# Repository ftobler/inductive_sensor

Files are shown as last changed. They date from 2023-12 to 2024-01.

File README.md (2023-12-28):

# inductive sensor with STM32

This is a open source inductive sensor using a STM32G030K8T6 MCU.

pcb-inductive-sensor v1

---

PCB has been made with Eagle, Software with STM32CubeIDE.

The sensor is capable of sub mm accuracy. There might be linearity errors.

The TX coil is driven with 125kHz. A new measurement can be made every 50ms. The speed is limited mainly due to lack of processing power and FPU. During one measurement, the TX coil is ON for 2.8ms. During the short ON time, data is gathered which is later processed. The amount which can be gathered is limited by RAM available.

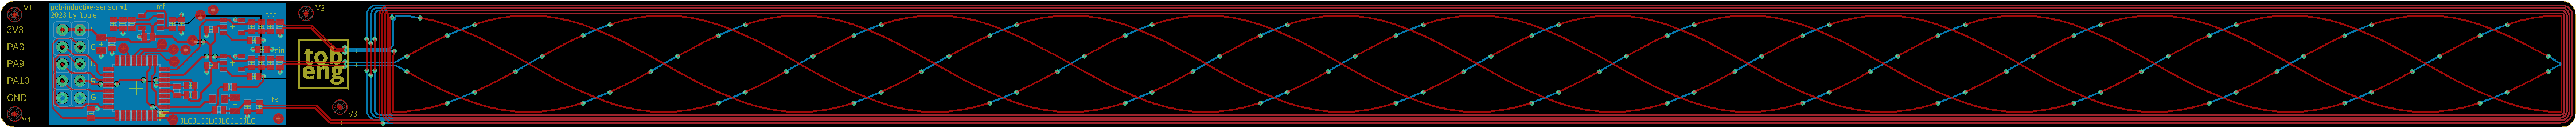
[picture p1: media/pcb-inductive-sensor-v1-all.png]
pcb-inductive-sensor v1


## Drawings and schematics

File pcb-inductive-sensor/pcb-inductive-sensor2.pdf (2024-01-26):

GND ¹⁰⁰n +3V³ | +3V³ GND
GND ⁺³V³ | 100n

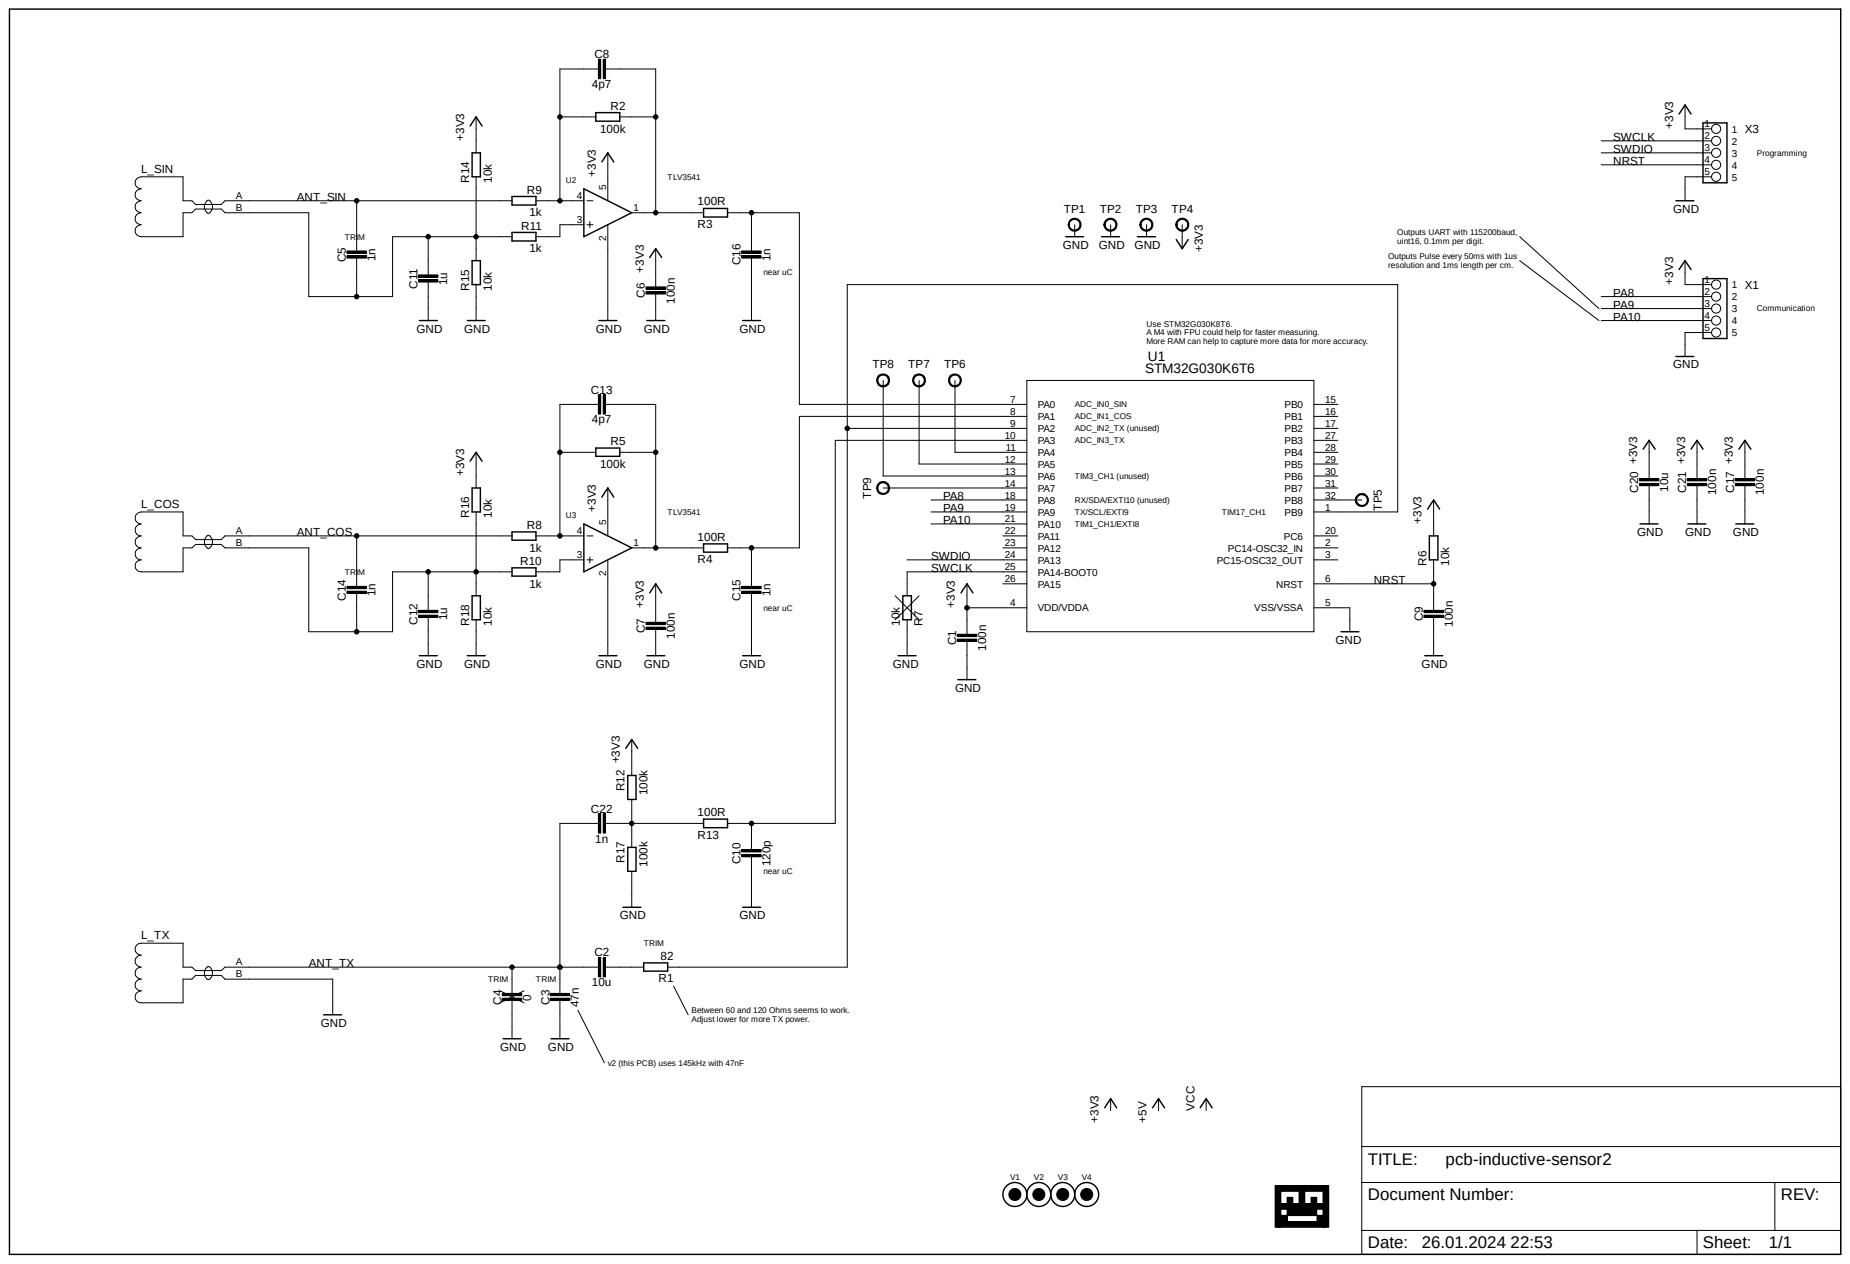
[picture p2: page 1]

Outputs UART with 115200baud,
uint16, 0.1mm per digit.
Outputs Pulse every 50ms with 1us
resolution and 1ms length per cm.

Use STM32G030K8T6.
A M4 with FPU could help for faster measuring.
More RAM can help to capture more data for more accuracy.

PA1 8
PA2 9
PA3 10
PA4 11

Between 60 and 120 Ohms seems to work.
Adjust lower for more TX power.

v2 (this PCB) uses 145kHz with 47nF

Document Number: | REV:

Date: 26.01.2024 22:53 | Sheet: 1/1

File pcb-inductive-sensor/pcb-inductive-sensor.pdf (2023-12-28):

GND ¹⁰⁰n +3V³ | +3V³ GND
GND ⁺³V³ | 100n

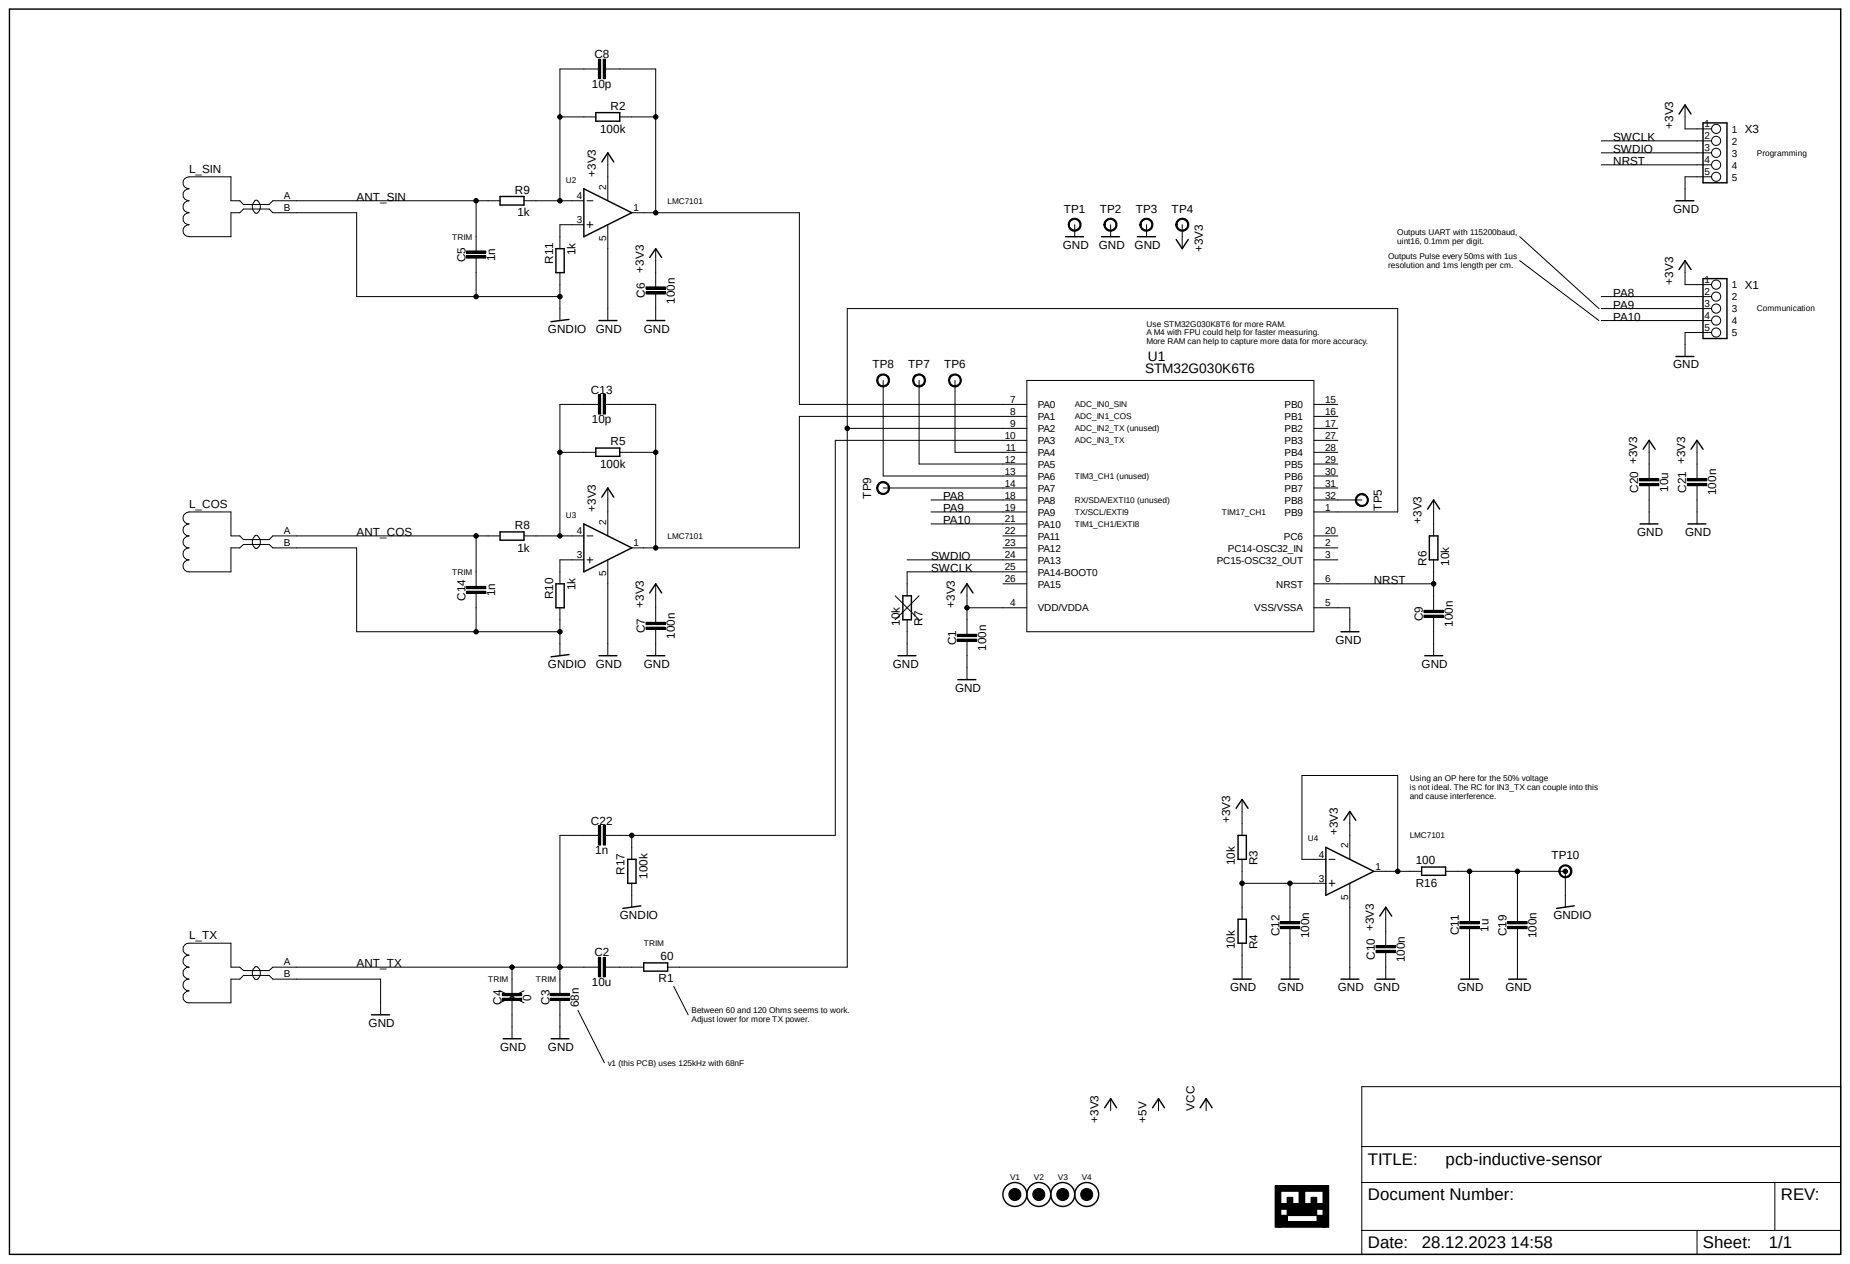
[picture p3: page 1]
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

Use STM32G030K8T6 for more RAM.
A M4 with FPU could help for faster measuring.
More RAM can help to capture more data for more accuracy.

PA1 8
PA2 9
PA3 10
PA4 11

Using an OP here for the 50% voltage
is not ideal. The RC for IN3_TX can couple into this
and cause interference.

Between 60 and 120 Ohms seems to work.
Adjust lower for more TX power.

v1 (this PCB) uses 125kHz with 68nF

Document Number: | REV:

Date: 28.12.2023 14:58 | Sheet: 1/1

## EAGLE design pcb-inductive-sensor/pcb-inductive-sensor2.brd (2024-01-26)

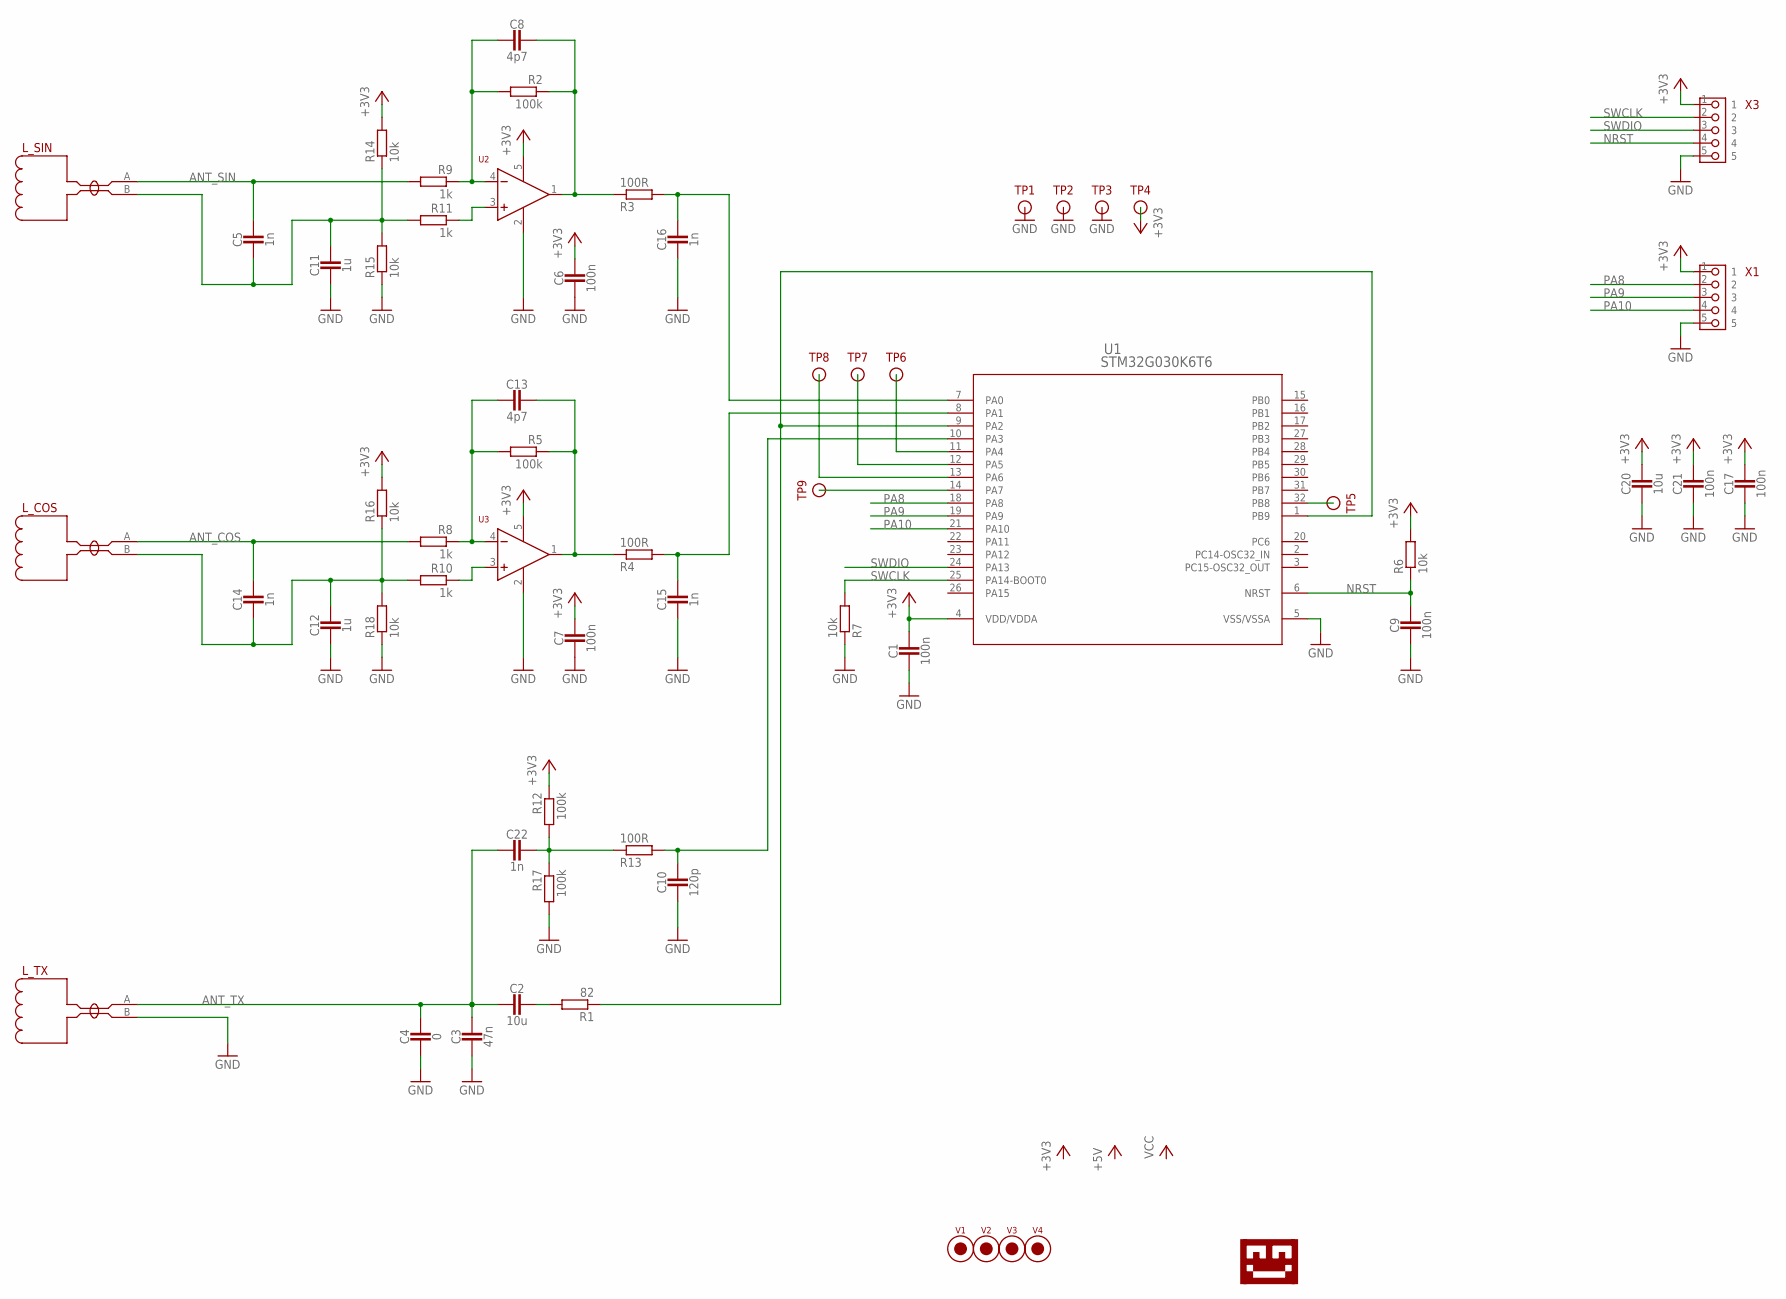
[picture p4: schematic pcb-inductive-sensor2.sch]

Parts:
C1, C6, C7, C9, C17, C21: 100n; 0603_CAP
C2, C20: 10u; 0805_CAP
C3: 47n; 0603_CAP
C4: 0; 0603_CAP
C5, C14, C15, C16, C22: 1n; 0603_CAP
C8, C13: 4p7; 0603_CAP
C10: 120p; 0603_CAP
C11, C12: 1u; 0603_CAP
L_COS: INDUCTION_SENSOR; INDUCTIVE_SENSOR_NET_TIE
L_SIN: INDUCTION_SENSOR; INDUCTIVE_SENSOR_NET_TIE
L_TX: INDUCTION_SENSOR; INDUCTIVE_SENSOR_NET_TIE
R1: 82; 0805_RES
R2, R5, R12, R17: 100k; 0603-RES
R3, R4, R13: 100R; 0603-RES
R6, R7, R14, R15, R16, R18: 10k; 0603-RES
R8, R9, R10, R11: 1k; 0603-RES
TP1, TP2, TP3, TP4, TP5, TP6, TP7, TP8, TP9: TESTPIN; PIN-SMD-1X1-TEST_1M5
U1: STM32G030K6T6; LQFP-32
U2, U3: OPAMP-TLV3541IDBVT; SOT-23-5
U$1: LOGO-TOBENG-1MM-FINISH; TOBENG-1MM-FINISH
V1, V2, V3, V4: FIDUCIAL2MM; FIDUCIAL_2MM
X1, X3: PIN_5X1HD; PIN_5X1_HD

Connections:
+3V3: C1.1, C6.1, C7.1, C17.1, C20.P$1 (1), C21.1, R6.2, R12.1, R14.2, R16.2, TP4.1, U1.4 (VDD/VDDA), U2.5 (VCC), U3.5 (VCC), X1.1, X3.1
ANT_COS: C14.1, L_COS.A, R8.2
ANT_SIN: C5.1, L_SIN.A, R9.2
ANT_TX: C2.P$2 (2), C3.1, C4.1, C22.2, L_TX.A
ANT_TX1: R1.1, U1.1 (PB9), U1.9 (PA2)
GND: C1.2, C3.2, C4.2, C6.2, C7.2, C9.2, C10.2, C11.2, C12.2, C15.2, C16.2, C17.2, C20.P$2 (2), C21.2, L_TX.B, R7.1, R15.1, R17.2, R18.1, TP1.1, TP2.1, TP3.1, U1.5 (VSS/VSSA), U2.2 (GND), U3.2 (GND), X1.5, X3.5
unnamed: C16.1, R3.2, U1.7 (PA0)
unnamed: C15.1, R4.2, U1.8 (PA1)
unnamed: C10.1, R13.2, U1.10 (PA3)
unnamed: TP6.1, U1.11 (PA4)
unnamed: TP7.1, U1.12 (PA5)
unnamed: TP8.1, U1.13 (PA6)
unnamed: TP9.1, U1.14 (PA7)
unnamed: C8.1, R2.1, R3.1, U2.1 (OUT)
unnamed: C8.2, R2.2, R9.1, U2.4 (-)
unnamed: TP5.1, U1.32 (PB8)
unnamed: C13.1, R4.1, R5.1, U3.1 (OUT)
unnamed: C13.2, R5.2, R8.1, U3.4 (-)
unnamed: C22.1, R12.2, R13.1, R17.1
unnamed: R11.1, U2.3 (+)
unnamed: R10.1, U3.3 (+)
unnamed: C2.P$1 (1), R1.2
unnamed: C12.1, C14.2, L_COS.B, R10.2, R16.1, R18.2
unnamed: C5.2, C11.1, L_SIN.B, R11.2, R14.1, R15.2
NRST: C9.1, R6.1, U1.6 (NRST), X3.4
PA8: U1.18 (PA8), X1.2
PA9: U1.19 (PA9), X1.3
PA10: U1.21 (PA10), X1.4
SWCLK: R7.2, U1.25 (PA14-BOOT0), X3.2
SWDIO: U1.24 (PA13), X3.3

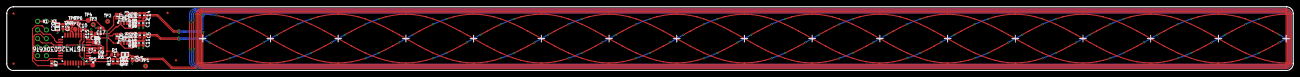
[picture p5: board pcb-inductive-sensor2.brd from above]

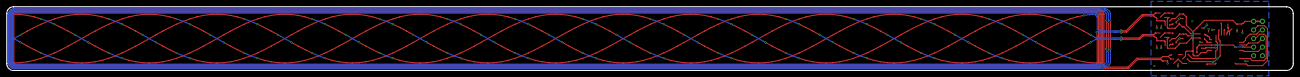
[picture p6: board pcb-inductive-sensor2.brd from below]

Board: 2 copper layers, 380.0 x 18.8 mm, 60 parts (2 on the bottom side), 30 nets.

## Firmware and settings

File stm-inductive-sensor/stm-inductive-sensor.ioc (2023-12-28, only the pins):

Mcu.UserName=STM32G030K8Tx
PA0.Signal=ADC1_IN0
PA1.Signal=ADC1_IN1
PA10.Signal=GPIO_Output
PA13.Signal=SYS_SWDIO
PA14-BOOT0.Signal=SYS_SWCLK
PA3.Signal=ADC1_IN3
PA8.Signal=S_TIM1_CH1
PA9.Signal=USART1_TX
PB7.Signal=USART1_RX
PB9.Signal=S_TIM17_CH1

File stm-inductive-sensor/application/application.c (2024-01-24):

/*
 * application.c
 *
 *  Created on: Dec 27, 2023
 *      Author: ftobler
 */


#include "application.h"
#include "stm32_hal.h"
#include "stdint.h"
#include "string.h"
#include "math.h"

extern ADC_HandleTypeDef hadc1;
extern DMA_HandleTypeDef hdma_adc1;
extern TIM_HandleTypeDef htim17;
extern TIM_HandleTypeDef htim1;
extern UART_HandleTypeDef huart1;

#define DATASIZE 1300  //maximize this. RAM amount and processing power is the limiting factor
#define DATAWIDTH 2
static uint16_t dma_buf[DATASIZE*DATAWIDTH];
static uint32_t dma_finish = 0;
static uint32_t task_start = 0;


//calibration to cancel out interference on the PCB by digitally mixing the TX signal in the receive paths.
//it no metal is near the sensor strip, the app.sin and app.cos variables should hover around 0.
//for ARR=512
static float coupling_cal_sin = -0.0079f; //to cancel out signal bleed in from TX
static float coupling_cal_cos =  0.1511f; //to cancel out signal bleed in from TX
static uint32_t coupling_auto_cal = 0;  //set 1 to execute. execute without metal near strip

static uint32_t frequency_auto_cal = 0;  //set 1 to execute. put metal on strip


static void main_task();
static void process_data_sin();
static void process_data_cos();
static void process_data_final();
static void coupling_auto_cal_fn();
static void frequency_auto_cal_fn();

typedef struct {
	float sin;
	float cos;
	float amplitude;
	float angle;
	float distance;
	float distance_filter;
	int n;
} App_t;

static volatile App_t app = {0};

void application_init() {
	//timer 1 is used for re-starting the measurement task and to output the result
	//on PWM channel 1 (PA8). 1ms <=> 1cm
	//measurement runs every 50ms and is also controlled through this timer
	HAL_TIM_Base_Start_IT(&htim1);
	HAL_TIM_PWM_Start(&htim1, TIM_CHANNEL_1);

	//timer17 is used to generate the TX coil signal.
	//the PWM is always active, but set to 0 for no output
    HAL_TIM_PWM_Start(&htim17, TIM_CHANNEL_1);
	htim17.Instance->CCR1 = 0; //capture compare (PWM value) / off - will be set to 50% of ARR when ON.
	htim17.Instance->ARR = 440; //auto reload register / this sets the TX frequency

	//calibrate the ADC
	//the adc is configured with DMA and set to 2 channel scan.
	//the actual channels are set in the measuring task.
    HAL_ADCEx_Calibration_Start(&hadc1);
	HAL_Delay(10);

}

void appliation_loop() {
	if (task_start) {
		task_start = 0;
		main_task();

		if (coupling_auto_cal) {
			coupling_auto_cal_fn();
		}

		if (frequency_auto_cal) {
			frequency_auto_cal_fn();
		}
	}
}


/**
 * Do one measurement. Taskes ~40ms depending on how large the DMA buffer is.
 * Main time is spent in calculations, this is originally made for a STM32G030 without FPU.
 *
 * To prevent asymmetry in measurements, the ADC DMA is started 2 times. First to capture the sine signal and the tx
 * and then to capture the cosine and the tx. Tx is captured for a simplified lock-in amplifier. The lock-in is missing a
 * discrete sine/cosine path because in this application the phase is fixed and only the amplitude (with sign) is needed.
 *
 * The ADC is set to a relatively high sampling rate. It is critical that the two measured signals do not have a big
 * delay between them. Due to the high sampling rate, the DMA buffer is filled fast.
 */
void main_task() {
	ADC_ChannelConfTypeDef sConfig = {0};


	//// SINE CAPTURE ////

	//start the timer to generate PWM for the TX coil
	htim17.Instance->CCR1 = htim17.Instance->ARR / 2;
	//delay so the DC goes away
	volatile uint16_t i;
	i = 300; while (i--);


	//configure ADC channels to capture
	sConfig.Channel = ADC_CHANNEL_3;
	sConfig.Rank = ADC_REGULAR_RANK_1;
	sConfig.SamplingTime = ADC_SAMPLINGTIME_COMMON_1;
	if (HAL_ADC_ConfigChannel(&hadc1, &sConfig) != HAL_OK)
		while(1);
	sConfig.Channel = ADC_CHANNEL_0;
	sConfig.Rank = ADC_REGULAR_RANK_2;
	sConfig.SamplingTime = ADC_SAMPLINGTIME_COMMON_1;
	if (HAL_ADC_ConfigChannel(&hadc1, &sConfig) != HAL_OK)
		while(1);

	//start the DMA transfer
	dma_finish = 0;
	HAL_ADC_Start_DMA(&hadc1, (uint32_t*)dma_buf, DATASIZE*DATAWIDTH);
	//wait for the DMA finish interrupt (flag DMA_FLAG_TC1)
	while (dma_finish == 0);
	//stop the PWM
	htim17.Instance->CCR1 = 0;

	//finish calculations
	process_data_sin();


	//// COSINE CAPTURE ////

	//start the timer to generate PWM for the TX coil
	htim17.Instance->CCR1 = htim17.Instance->ARR / 2;
	//delay so the DC goes away
	i = 300; while (i--);

	//configure ADC channels to capture
	sConfig.Channel = ADC_CHANNEL_3;
	sConfig.Rank = ADC_REGULAR_RANK_1;
	sConfig.SamplingTime = ADC_SAMPLINGTIME_COMMON_1;
	if (HAL_ADC_ConfigChannel(&hadc1, &sConfig) != HAL_OK)
		while(1);
	sConfig.Channel = ADC_CHANNEL_1;
	sConfig.Rank = ADC_REGULAR_RANK_2;
	sConfig.SamplingTime = ADC_SAMPLINGTIME_COMMON_1;
	if (HAL_ADC_ConfigChannel(&hadc1, &sConfig) != HAL_OK)
		while(1);

	//start the DMA transfer
	dma_finish = 0;
	HAL_ADC_Start_DMA(&hadc1, (uint32_t*)dma_buf, DATASIZE*DATAWIDTH);
	//wait for the DMA finish interrupt (flag DMA_FLAG_TC1)
	while (dma_finish == 0);

	//stop the PWM
	htim17.Instance->CCR1 = 0;
	//finish calculations
	process_data_cos();


	//// FINISH AND OUTPUT MEASUREMENT ////

	//process all data
	process_data_final();

	//wait for next conversion
	//HAL_Delay(5);
	int ticks = app.distance_filter * 100;
	if (ticks < 10) {
		ticks = 10;
	}
	if (ticks > 40000) {
		ticks = 40000;
	}
	htim1.Instance->CCR1 = ticks;

	static uint16_t distance = 0;
	distance = app.distance_filter * 10;
	HAL_UART_Transmit_DMA(&huart1, (uint8_t*)&distance, sizeof(distance));
}

/**
 * ISR
 * interrupt on ADC DMA complete.
 */
void application_dma_complete_isr() {
	dma_finish = 1;
}

/**
 * ISR
 * interrupt on timer1 complete and ready to start new measurement
 */
void application_timer_isr() {
	task_start = 1;
}


//macros to extract the right values from the DMA buffer
#define get_sin(x) (dma_buf[(x)*DATAWIDTH+1])
#define get_cos(x) (dma_buf[(x)*DATAWIDTH+1])
#define get_tx(x)  (dma_buf[(x)*DATAWIDTH+0])



__attribute__((optimize("-O3")))
static void process_data_sin() {

	float avg_tx = 0.0f;
	float sum_sin = 0.0f;
	const int n = DATASIZE;

	//need to get rid of DC in the LO/TX channel
	//the sin channel is allowed to have DC
	for (int i = 0; i < n; i++) {
		avg_tx  += get_tx(i);
	}
	avg_tx  = avg_tx  / n;

	for (int i = 0; i < n; i++) {
		float tx_hp  = get_tx(i)  - avg_tx;
		float sin_hp = get_sin(i) + tx_hp * coupling_cal_sin;
		sum_sin = sum_sin + sin_hp * tx_hp;
	}
	app.sin = sum_sin / n / 4096;

}
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

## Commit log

2023-12-27 stm32 project running prototype
2023-12-28 higher output accuracy, more samples, less computations
2023-12-28 eagle pcb with improvement comments
    [pcb-inductive-sensor.brd, pcb-inductive-sensor.sch]
2024-01-24 calibration for 2nd pcb revision
2024-01-26 pcb version 2
    [pcb-inductive-sensor2.brd, pcb-inductive-sensor2.sch]
2024-01-26 gerber data

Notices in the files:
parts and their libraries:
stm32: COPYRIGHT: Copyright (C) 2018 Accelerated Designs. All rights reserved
